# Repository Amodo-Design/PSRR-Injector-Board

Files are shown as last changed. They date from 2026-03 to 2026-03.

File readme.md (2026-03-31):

# PSRR Injector Board

Board to allow you to measure power supply rejection ratio.

Allows you to inject an AC ripple on top of your DC power supply to measure downstream. 0dB from 100Hz+. 

**[Product page](https://amodo-design.github.io/STAGING_AMODO_WEBSITE_SW/products/psrr-injector-board/)(https://amododesign.com/products/psrr-injector-board/)) · Designed by [Amodo](https://amododesign.com)**

## How it works

A clean lab supply connects on one side, and your DUT on the other. A function generator creates a signal that is AC-coupled onto the supply rail, superimposing a small ripple on top of the DC. Large series inductance (1000 µH) between the coupling node and the supply input forms an LC filter with the injection caps (880 µF per rail), keeping the supply clean and avoiding backfeed into the supply's regulation loop.

The circuit is mirrored so you can inject on either the positive or negative rail.

Note: the input impedance of your supply may be fairly low, so you may need a power amplifier between your function generator and the PSRR board. 

## Specifications

| Parameter | Value |
|---|---|
| Max voltage | ±30 V |
| Max current | 1 A |
| Injection capacitance | 880 µF per rail |
| Series inductance | 1000 µH per rail |
| Flat band | 100 Hz – 1 MHz+ |
| Low-frequency rolloff | 20 dB/dec below 100 Hz |
| Usable range | ~1 Hz (with calibration) |
| Supply input | 4 mm banana plugs |
| DUT output | 4 mm banana plugs |
| Signal injection | SMA |

## Repo layout

```
hardware/          KiCad project — schematic, PCB layout, 3D model
simulation/        LTSpice simulation file and component models
```

## Getting started

**PCB** — Open `hardware/AMODO_PSRR_INJECTOR_CBs_1.kicad_pro` in KiCad 6+.

**Simulation** — Open `simulation/psrr.asc` in LTSpice.

## License

Open-source hardware. Gerbers, schematics, and BOM are freely available — fabricate it yourself or send to your favourite PCB house.

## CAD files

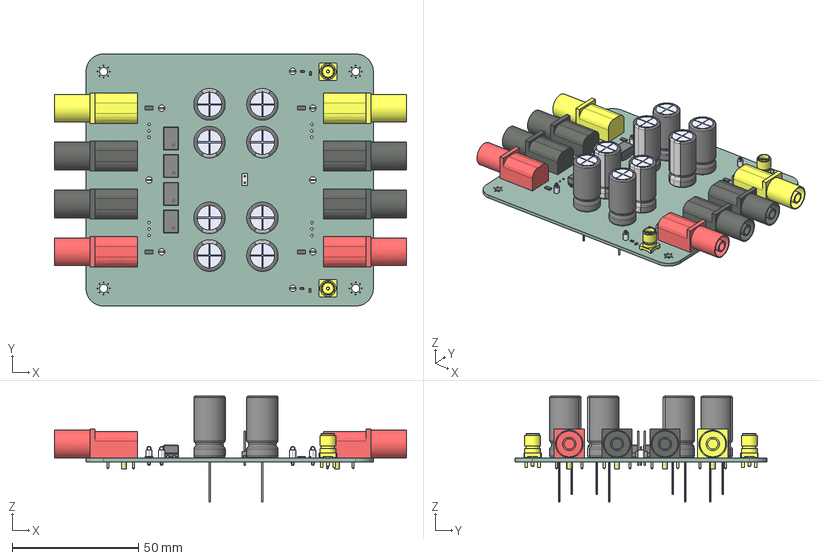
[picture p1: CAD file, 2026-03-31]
hardware/AMODO_PSRR_INJECTOR_CBs_1.step
139.7 x 100.0 x 42.0 mm
S16N-PC-RED x 2
ECA1HM102 x 8
SMA-J-P-H-ST-TH1 x 2
S16N-PC-YELLOW x 2
R_1206_3216Metric x 4
R_0603_1608Metric x 4
keystone-PN5002 x 8
S16N-PC-BLACK x 4
c-5-146252-1-d-3d
AMODO_PSRR_INJECTOR_CBs_1_PCB

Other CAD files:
hardware/outputs/AMODO_PSRR_INJECTOR_CBs_1_v1.0.0/3D/AMODO_PSRR_INJECTOR_CBs_1_v1.0.0.step

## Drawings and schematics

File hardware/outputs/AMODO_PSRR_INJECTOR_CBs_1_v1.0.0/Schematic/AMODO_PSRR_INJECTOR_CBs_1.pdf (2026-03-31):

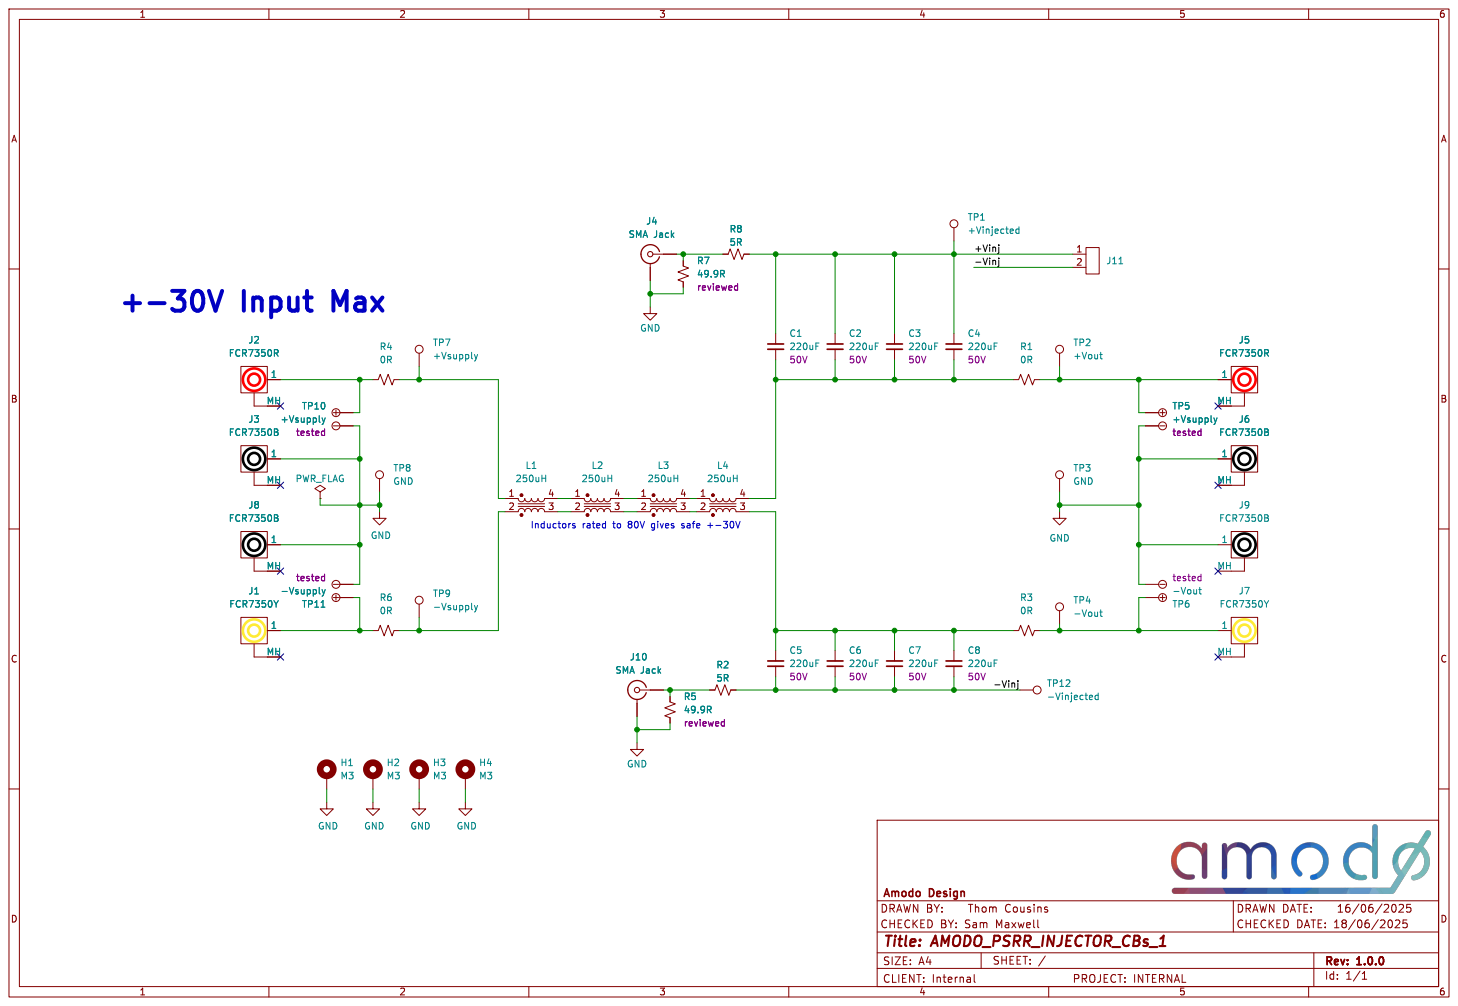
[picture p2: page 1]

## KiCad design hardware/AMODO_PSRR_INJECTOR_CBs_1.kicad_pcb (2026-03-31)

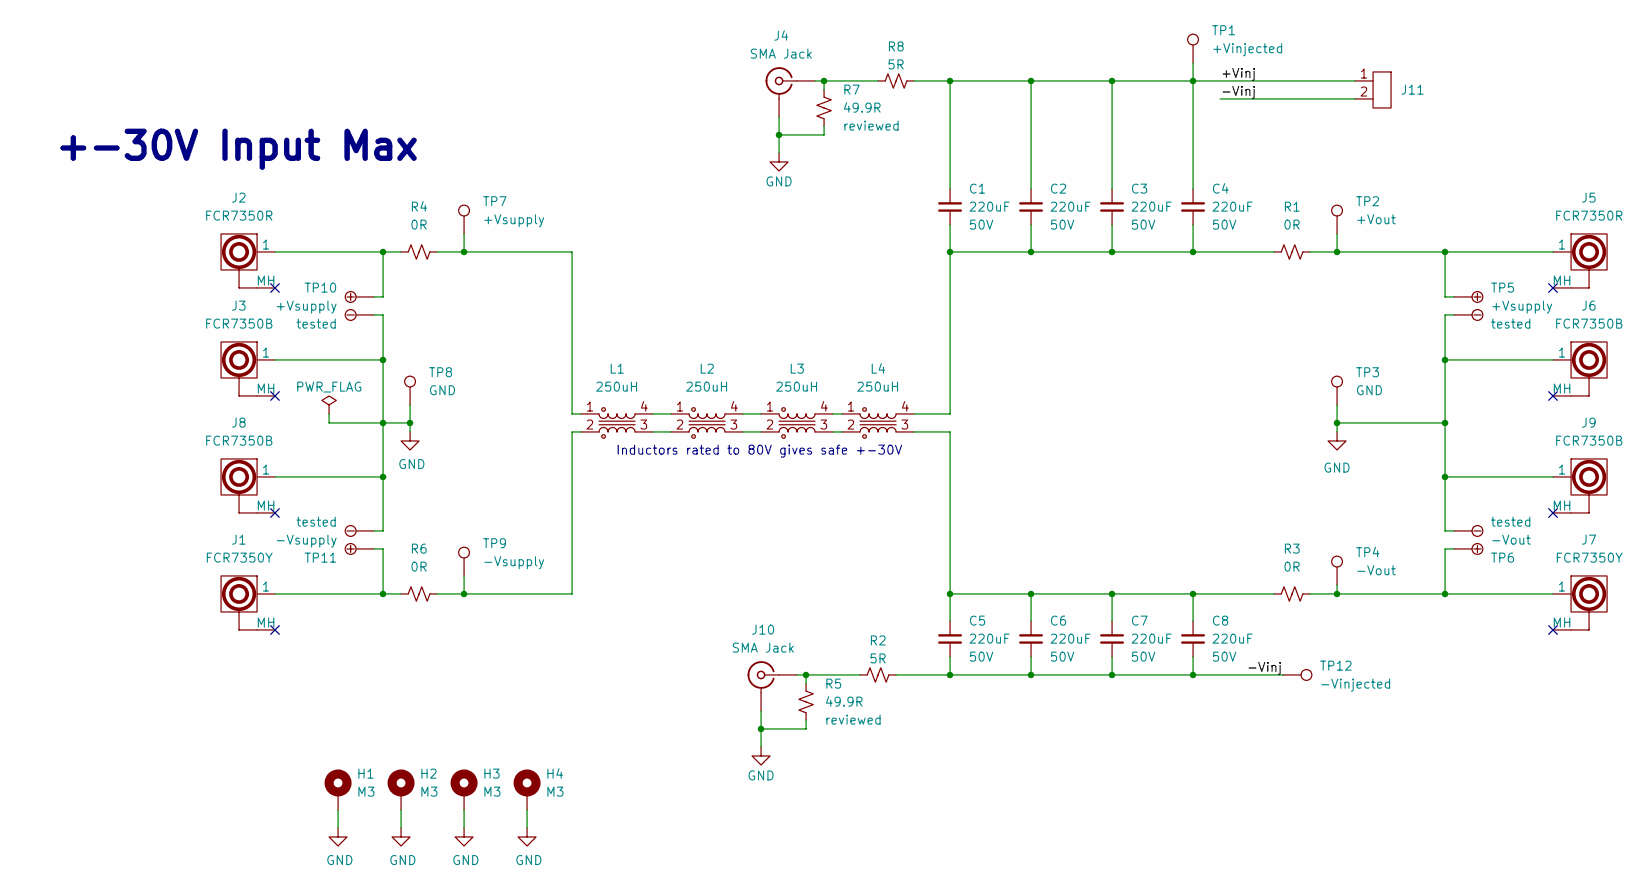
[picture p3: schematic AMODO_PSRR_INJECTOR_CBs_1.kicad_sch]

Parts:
C1, C2, C3, C4, C5, C6, C7, C8: 220uF; C_ALU_D12.5_L25_THT; Voltage 50V; mpn UEP1H221MHD
H1, H2, H3, H4: M3; MountingHole_3.2mm_M3_Pad
J1, J7: FCR7350Y; S16N-PC-YELLOW; mpn FCR7350Y
J2, J5: FCR7350R; S16N-PC-RED; mpn FCR7350R
J3, J6, J8, J9: FCR7350B; S16N-PC-BLACK; mpn FCR7350B
J4, J10: SMA Jack; SMA-J-P-H-ST-TH1; mpn SMA-J-P-H-ST-TH1
J11: 5-146252-1; mpn 5-146252-1|530153-2
L1, L2, L3, L4: 250uH; 744224; mpn 744224
R1, R3, R4, R6: 0R; R_1206_3216Metric; mpn RCC12060000Z0EA
R2, R8: 5R; R_0603_1608Metric; mpn CSRT0603FT5R00
R5, R7: 49.9R; R_0603_1608Metric; mpn ERJ-3EKF49R9V
TP1: +Vinjected; KeystoneMiniatureTestLoop; mpn 5002
TP2: +Vout; KeystoneMiniatureTestLoop; mpn 5002
TP3, TP8: GND; KeystoneMiniatureTestLoop; mpn 5002
TP4: -Vout; KeystoneMiniatureTestLoop; mpn 5002
TP5, TP10: +Vsupply; TestPoint_Dual_D1.5mm_H1.0mm
TP6: -Vout; TestPoint_Dual_D1.5mm_H1.0mm
TP7: +Vsupply; KeystoneMiniatureTestLoop; mpn 5002
TP9: -Vsupply; KeystoneMiniatureTestLoop; mpn 5002
TP11: -Vsupply; TestPoint_Dual_D1.5mm_H1.0mm
TP12: -Vinjected; KeystoneMiniatureTestLoop; mpn 5002

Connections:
/+Vinj: C1.1, C2.1, C3.1, C4.1, J11.1, R8.2, TP1.1
/-Vinj: C5.2, C6.2, C7.2, C8.2, J11.2, R2.2, TP12.1
GND: H1.1, H2.1, H3.1, H4.1, J3.1, J4.2 (Ext), J6.1, J8.1, J9.1, J10.2 (Ext), R5.2, R7.2, TP3.1, TP5.2, TP6.2, TP8.1, TP10.2, TP11.2
unnamed: C1.2, C2.2, C3.2, C4.2, L4.4, R1.1
unnamed: C5.1, C6.1, C7.1, C8.1, L4.3, R3.1
unnamed: J1.1, R6.1, TP11.1
unnamed: J2.1, R4.1, TP10.1
unnamed: J4.1 (In), R7.1, R8.1
unnamed: J5.1, R1.2, TP2.1, TP5.1
unnamed: J7.1, R3.2, TP4.1, TP6.1
unnamed: J10.1 (In), R2.1, R5.1
unnamed: L1.1, R4.2, TP7.1
unnamed: L1.2, R6.2, TP9.1
unnamed: L1.3, L2.2
unnamed: L1.4, L2.1
unnamed: L2.3, L3.2
unnamed: L2.4, L3.1
unnamed: L3.3, L4.2
unnamed: L3.4, L4.1

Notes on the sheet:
Inductors rated to 80V gives safe +-30V
+-30V Input Max

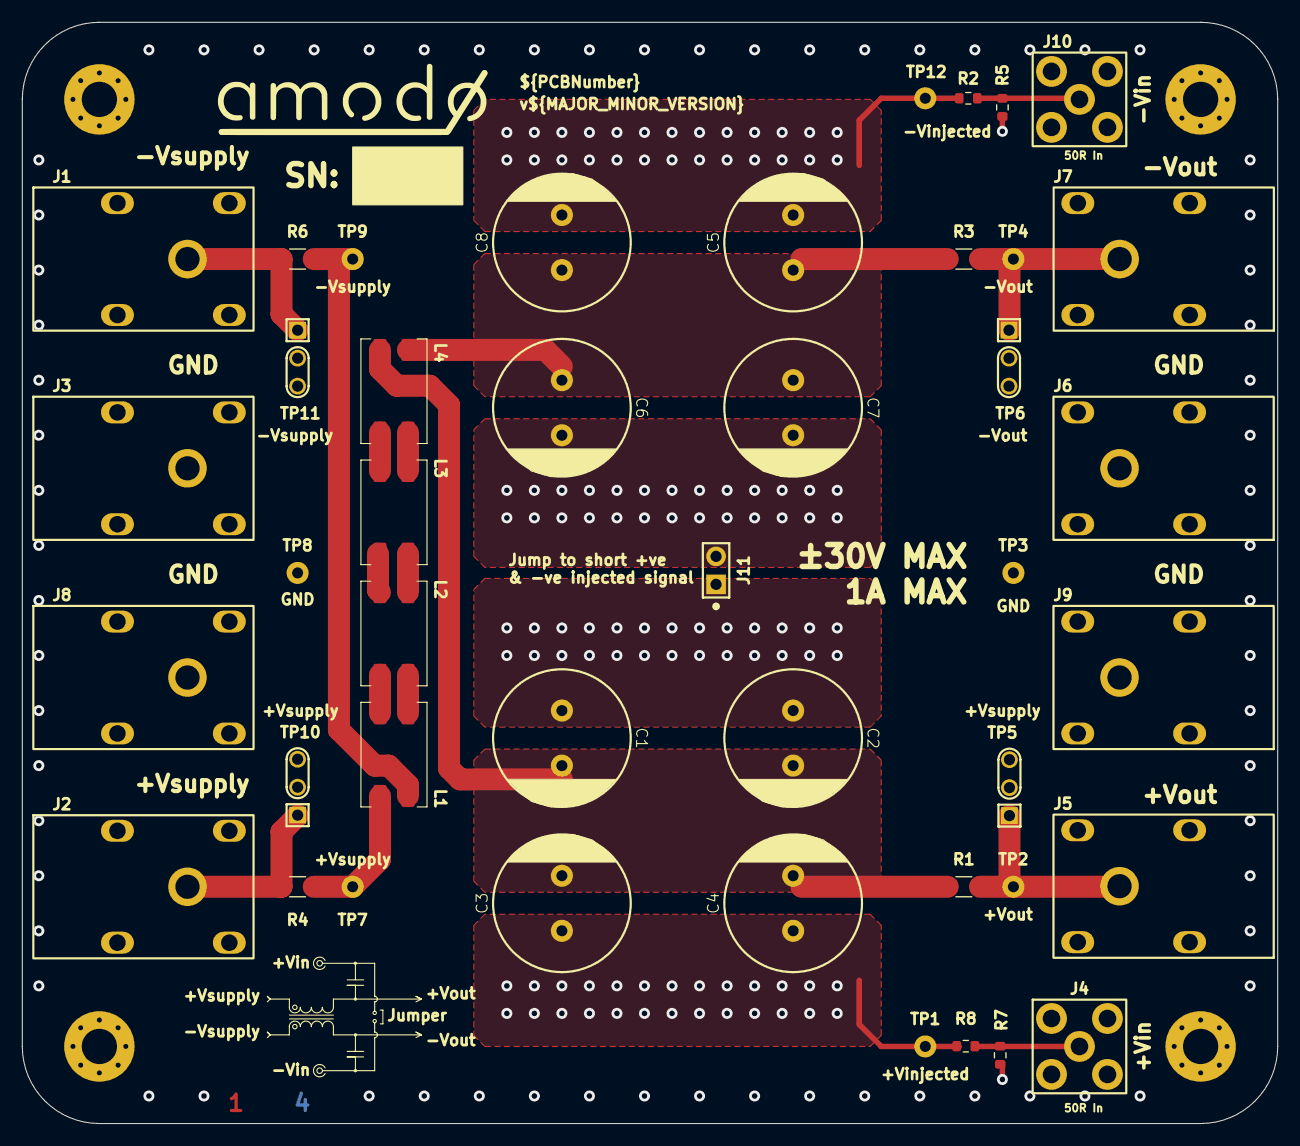
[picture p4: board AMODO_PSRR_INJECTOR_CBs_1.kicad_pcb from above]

Board: 4 copper layers, 114.0 x 100.0 mm, 47 parts (0 on the bottom side), 19 nets.
